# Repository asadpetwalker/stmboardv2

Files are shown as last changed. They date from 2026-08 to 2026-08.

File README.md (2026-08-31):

# stmboardv2

# What it is and why I made it
Initially, this was a standard better stm dev board, but as I progressed with this project, I realized I didn't want to do the exact same thing I did last time, so I added sensors and wireless capabilities, a speaker and more interfacing options, for extra security layers. Additionally, I added an ESP32 to sideload tasks, to add another programming option, and to add a microSD card peripheral to store more memory on my board. I made it because the STM is an extremely powerful chip, and my last board didn't do it justice from the lack of capabilities and GPIO, as well as the lack of indication leds and in general less than apt design. Thus, I spent much more time integrating multiple sensors and features, adding indicator LEDs and in general making it much more powerful and useful than a just a simple dev board.

# Assembly Instructions
1. Solder

# Pictures


Screenshot from 2026-08-30 23-37-19

# Bill of Materials

| LCSC# | MPN | Manufacturer | Package | Description | Quantity | Total Price ($) | Product Link |
|:---|:---|:---|:---|:---|---:|---:|:---|
| C29936 | CL10B105KA8NNNC | Samsung Electro-Mechanics | 0603 | 1uF ±10% 25V Ceramic Capacitor X7R 0603 | 20 | 0.43 | [Link](https://www.lcsc.com/product-detail/C29936.html) |
| C1705 | CL10A475KP8NNNC | Samsung Electro-Mechanics | 0603 | 4.7uF ±10% 10V Ceramic Capacitor X5R 0603 | 50 | 1 | [Link](https://www.lcsc.com/product-detail/C1705.html) |
| C13738 | X322516MLB4SI | YXC Crystal Oscillators | SMD3225-4P | Crystal 16MHz ±10ppm 9pF SMD3225-4P | 5 | 0.47 | [Link](https://www.lcsc.com/product-detail/C13738.html) |
| C164170 | 472192001 | MOLEX | SMD | Micro SD card (TF card) Connector and Ejector Hinged Lid Surface Mount | 1 | 0.73 | [Link](https://www.lcsc.com/product-detail/C164170.html) |
| C2933084  | FRC0402F2702TS | FOJAN | 0402 | 27kΩ ±1% 62.5mW 0402 Thick Film Resistor | 100 | 0.19 | [Link](https://www.lcsc.com/product-detail/C2933084.html)  |
| C2909342  | FRC0402F2700TS | FOJAN | 0402 | 270Ω ±1% 62.5mW 0402 Thick Film Resistor | 100 | 0.25 | [Link](https://www.lcsc.com/product-detail/C2909342.html)  |
| C1550542  | CP2102N-A02-GQFN20  | SILICON LABS | QFN-20-EP(3x3)  | USB to UART 3Mbps QFN-20-EP(3x3) Controllers RoHS | 1 | 2.29 | [Link](https://www.lcsc.com/product-detail/C1550542.html)  |
| C5656610  | ICS-43434 | TDK InvenSense | LGA-6(3.5x2.7)  | Omnidirectional -26dB 64dB LGA-6(3.5x2.7) Microphones RoHS | 1 | 4.13 | [Link](https://www.lcsc.com/product-detail/C5656610.html)  |
| C94355 | STM32F411RET6 | ST | LQFP-64(10x10)  | ARM Cortex-M4 32 Bit 100MHz LQFP-64(10x10) Microcontrollers RoHS | 1 | 6.87 | [Link](https://www.lcsc.com/product-detail/C94355.html) |
| C2913198  | ESP32-S3-WROOM-1-N8 | ESPRESSIF | SMD,25.5x18mm | 2.4GHz ESP32-S3 Chip On-board PCB Antenna -98.2dBm SMD,25.5x18mm RF Transceiver Modules and Modems RoHS | 1 | 4.91 | [Link](https://www.lcsc.com/product-detail/C2913198.html)  |
| C22365428 | AP2112K-1.8TRG1(MS) | MSKSEMI | SOT-23-5 | Linear Voltage Regulator IC Positive Fixed 1 Output 600mA SOT-23-5 | 5 | 0.48 | [Link](https://www.lcsc.com/product-detail/C22365428.html) |
| C726001 | ICM-20948 | TDK InvenSense | QFN-24(3x3) | QFN-24(3x3) IMUs (Inertial Measurement Units) RoHS | 1 | 18.96 | [Link](https://www.lcsc.com/product-detail/C726001.html) |
| C22469962 | TXB0102DCT(LX) | lingxingic | TSSOP-8 | 45Mbps 1 2 TSSOP-8 Translators, Level Shifters | 5 | 1.25 | [Link](https://www.lcsc.com/product-detail/C22469962.html) |
| C910544 | MAX98357AETE+T | MAXIM | TQFN-16-EP(3x3) | 2.4mA 2.5V~5.5V 3.2Wx1@4Ω Class D TQFN-16-EP(3x3) Audio Amplifiers RoHS | 1 | 1.32 | [Link](https://www.lcsc.com/product-detail/C910544.html) |
| C880859 | 0603N9R0C500CT | Walsin | 0603 | 9pF 50V Ceramic Capacitor NP0 0603 | 50 | 0.45 | [Link](https://www.lcsc.com/product-detail/C880859.html) |
| - | Custom PCB | JLCPCB | - | Custom printed circuit board | 5 | 8.34 | - |
| - | Shipping | - | - | Shipping cost | 1 | 18 | - |

**Total Estimated Cost:** $70.07

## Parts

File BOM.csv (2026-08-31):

Index | LCSC# | MPN | Manufacturer | Package | Customer # | Description | RoHS | Quantity | MOQ | Multiple | Unit Price($) | Extended Price($) | Product Link
1 | C29936 | CL10B105KA8NNNC | Samsung Electro-Mechanics | 0603 |  | 1uF ±10% 25V Ceramic Capacitor X7R 0603 | yes | 20 | 10 | 10 | 0.0216 | 0.43 | https://www.lcsc.com/product-detail/C29936.html
2 | C1705 | CL10A475KP8NNNC | Samsung Electro-Mechanics | 0603 |  | 4.7uF ±10% 10V Ceramic Capacitor X5R 0603 | yes | 50 | 50 | 50 | 0.0199 | 1.0 | https://www.lcsc.com/product-detail/C1705.html
3 | C13738 | X322516MLB4SI | YXC Crystal Oscillators | SMD3225-4P |  | Crystal 16MHz ±10ppm 9pF SMD3225-4P | yes | 5 | 5 | 5 | 0.0939 | 0.47 | https://www.lcsc.com/product-detail/C13738.html
4 | C164170 | 472192001 | MOLEX | SMD |  | Micro SD card (TF card) Connector and Ejector Hinged Lid Surface Mount | yes | 1 | 1 | 1 | 0.7313 | 0.73 | https://www.lcsc.com/product-detail/C164170.html
5 | C2933084 | FRC0402F2702TS | FOJAN | 0402 |  | 27kΩ ±1% 62.5mW 0402 Thick Film Resistor | yes | 100 | 100 | 100 | 0.0019 | 0.19 | https://www.lcsc.com/product-detail/C2933084.html
6 | C2909342 | FRC0402F2700TS | FOJAN | 0402 |  | 270Ω ±1% 62.5mW 0402 Thick Film Resistor | yes | 100 | 100 | 100 | 0.0025 | 0.25 | https://www.lcsc.com/product-detail/C2909342.html
7 | C1550542 | CP2102N-A02-GQFN20 | SILICON LABS | QFN-20-EP(3x3) |  | USB to UART 3Mbps QFN-20-EP(3x3) Controllers RoHS | yes | 1 | 1 | 1 | 2.2884 | 2.29 | https://www.lcsc.com/product-detail/C1550542.html
8 | C5656610 | ICS-43434 | TDK InvenSense | LGA-6(3.5x2.7) |  | Omnidirectional -26dB 64dB LGA-6(3.5x2.7) Microphones RoHS | yes | 1 | 1 | 1 | 4.1262 | 4.13 | https://www.lcsc.com/product-detail/C5656610.html
9 | C94355 | STM32F411RET6 | ST | LQFP-64(10x10) |  | ARM Cortex-M4 32 Bit 100MHz LQFP-64(10x10) Microcontrollers RoHS | yes | 1 | 1 | 1 | 6.8707 | 6.87 | https://www.lcsc.com/product-detail/C94355.html
10 | C2913198 | ESP32-S3-WROOM-1-N8 | ESPRESSIF | SMD,25.5x18mm |  | 2.4GHz ESP32-S3 Chip On-board PCB Antenna -98.2dBm SMD,25.5x18mm RF Transceiver Modules and Modems RoHS | yes | 1 | 1 | 1 | 4.91 | 4.91 | https://www.lcsc.com/product-detail/C2913198.html
11 | C22365428 | AP2112K-1.8TRG1(MS) | MSKSEMI | SOT-23-5 |  | Linear Voltage Regulator IC Positive Fixed 1 Output 600mA SOT-23-5 | yes | 5 | 5 | 5 | 0.0959 | 0.48 | https://www.lcsc.com/product-detail/C22365428.html
12 | C726001 | ICM-20948 | TDK InvenSense | QFN-24(3x3) |  | QFN-24(3x3) IMUs (Inertial Measurement Units) RoHS | yes | 1 | 1 | 1 | 18.9576 | 18.96 | https://www.lcsc.com/product-detail/C726001.html
13 | C22469962 | TXB0102DCT(LX) | lingxingic | TSSOP-8 |  | 45Mbps 1 2 TSSOP-8 Translators, Level Shifters | yes | 5 | 5 | 5 | 0.2506 | 1.25 | https://www.lcsc.com/product-detail/C22469962.html
14 | C910544 | MAX98357AETE+T | MAXIM | TQFN-16-EP(3x3) |  | 2.4mA 2.5V~5.5V 3.2Wx1@4Ω Class D TQFN-16-EP(3x3) Audio Amplifiers RoHS | yes | 1 | 1 | 1 | 1.3247 | 1.32 | https://www.lcsc.com/product-detail/C910544.html
15 | C880859 | 0603N9R0C500CT | Walsin | 0603 |  | 9pF 50V Ceramic Capacitor NP0 0603 | yes | 50 | 50 | 50 | 0.009 | 0.45 | https://www.lcsc.com/product-detail/C880859.html
16 | - | Custom PCB | JLCPCB | - |  | Custom printed circuit board | - | 5 | - | - | 1.668 | 8.34 | -
17 | - | Shipping | - | - |  | Shipping cost | - | 1 | - | - | 18.0 | 18.0 | -

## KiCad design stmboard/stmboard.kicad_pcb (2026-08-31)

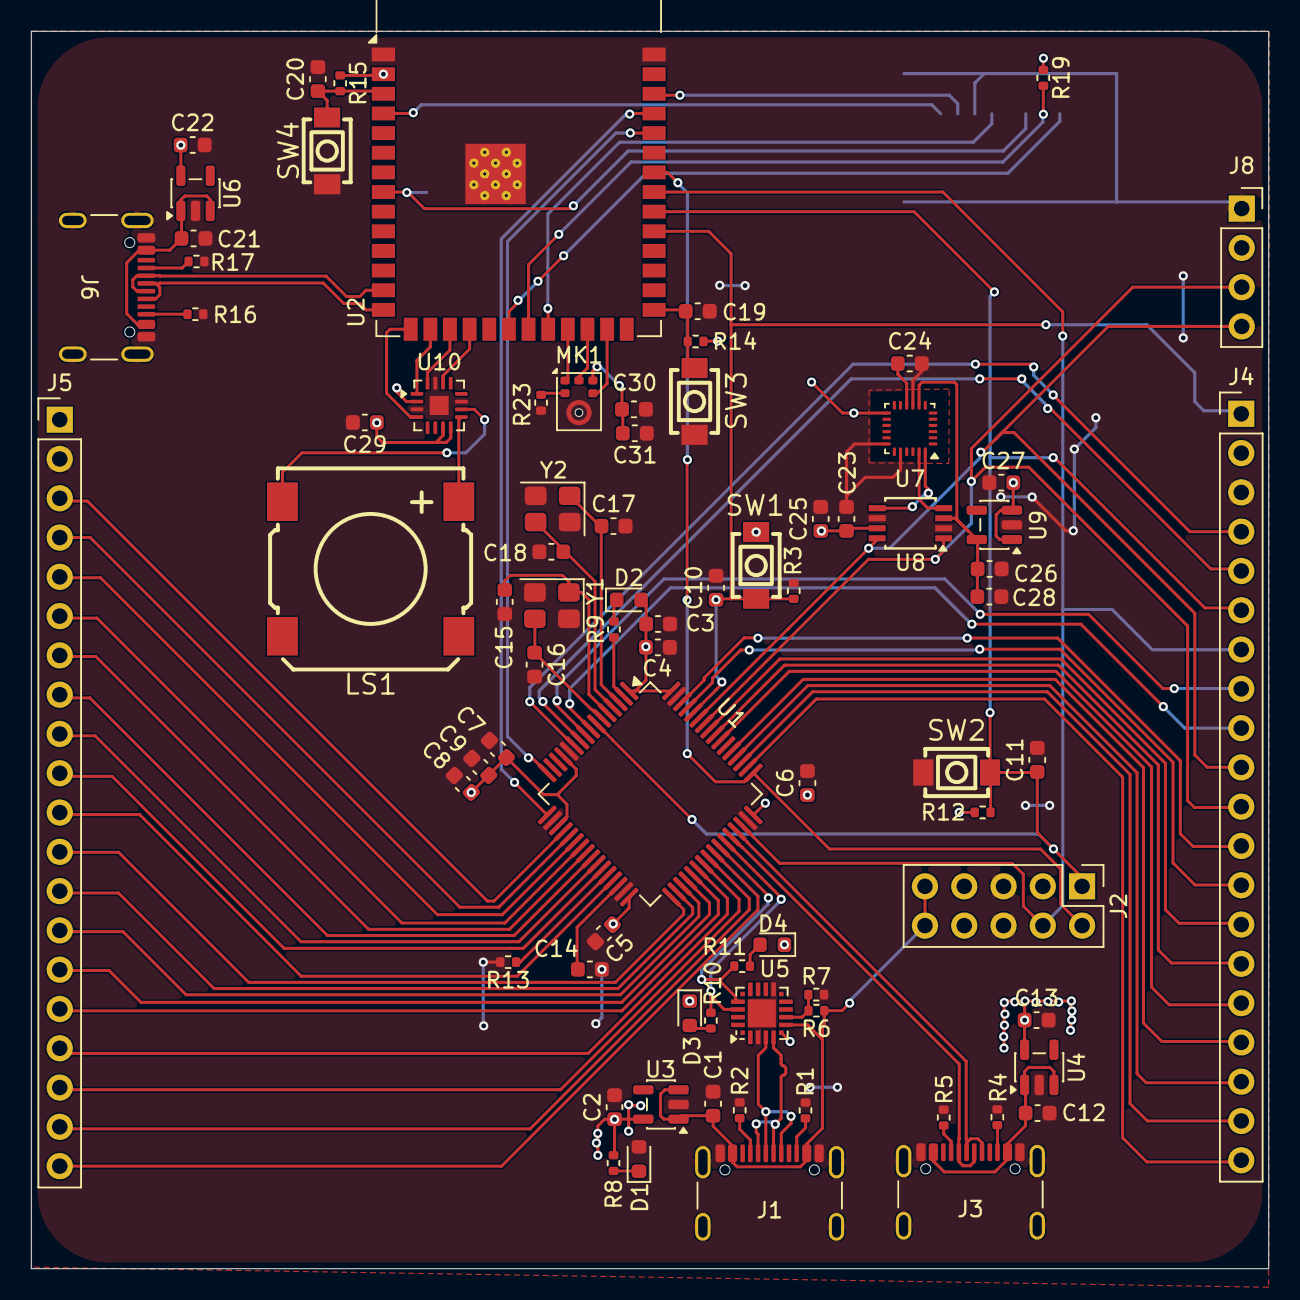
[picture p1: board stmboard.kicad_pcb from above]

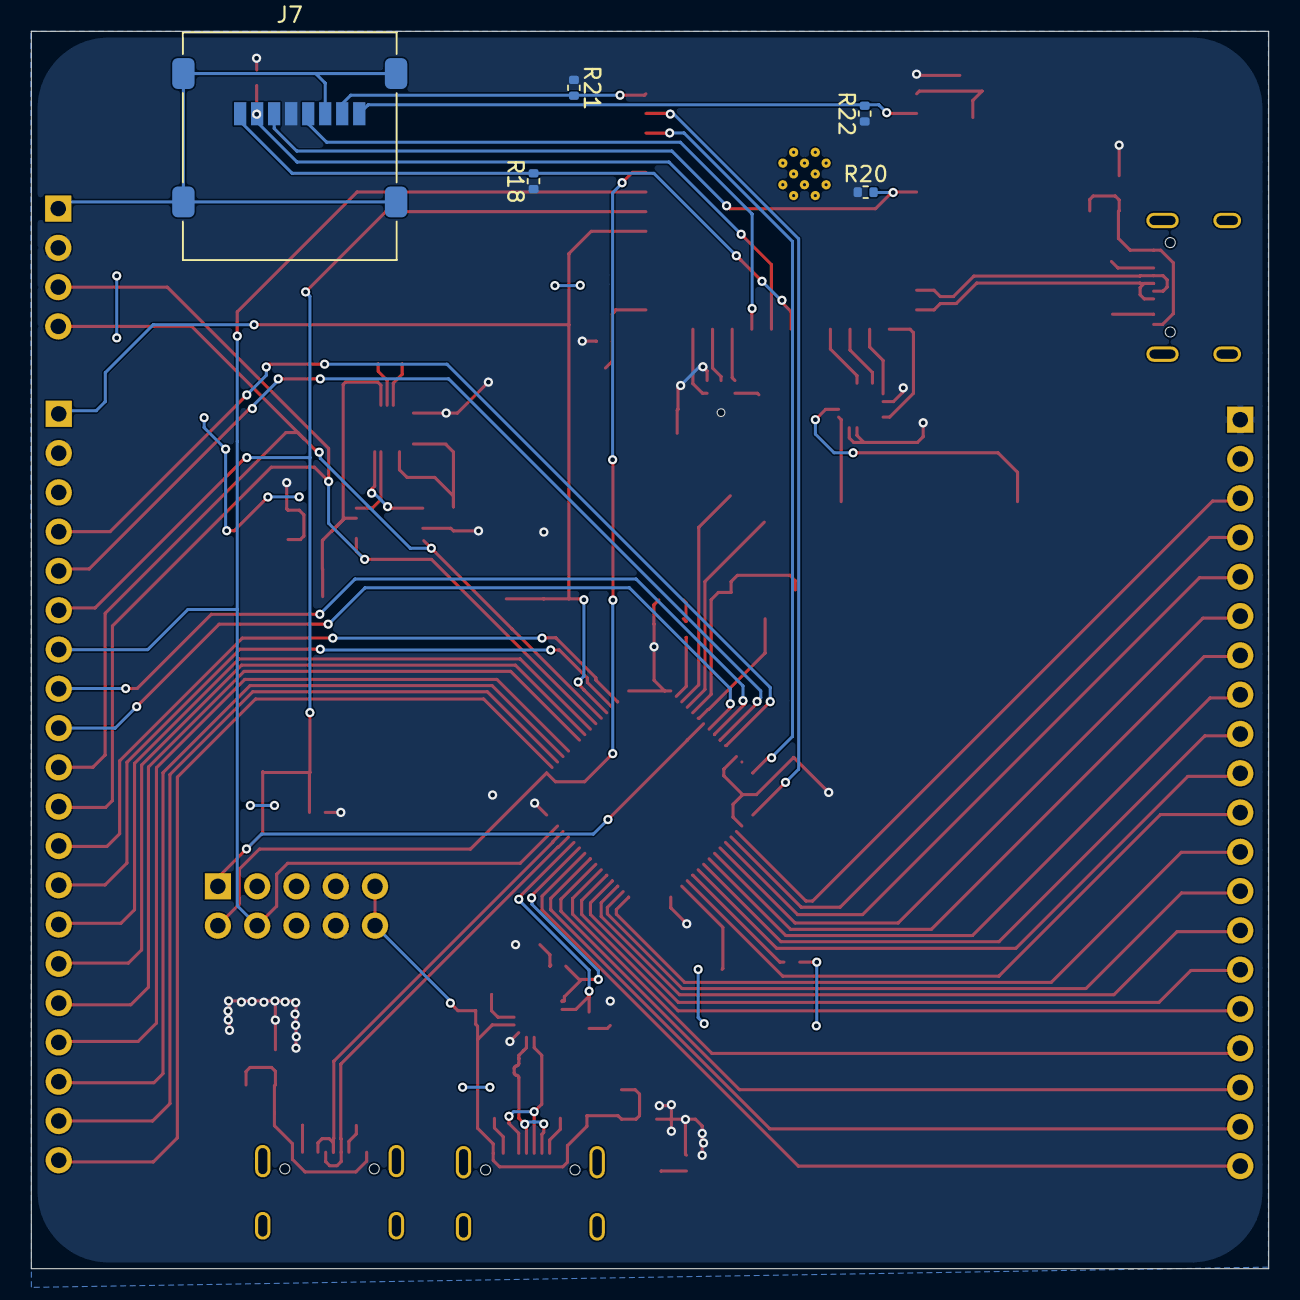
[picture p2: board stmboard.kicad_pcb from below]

Board: 2 copper layers, 80.0 x 80.0 mm, 84 parts (5 on the bottom side), 92 nets.

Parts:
C1, C2, C9, C12, C13, C21, C22, C27, C28: 1u; C_0603_1608Metric
C3, C4, C5, C6, C7, C10, C11, C14, C19, C20, C23, C24, C25, C26, C29, C30, C31: 100n; C_0603_1608Metric
C8: 4.7u; C_0603_1608Metric
C15, C16, C17, C18: 18p; C_0603_1608Metric
D1, D2: LED; LED_0603_1608Metric
D3: TX; LED_0603_1608Metric
D4: RX; LED_0603_1608Metric
J1, J3, J6: USB_C_Receptacle_USB2.0_14P; USB_C_Receptacle_GCT_USB4105-xx-A_16P_TopMnt_Horizontal
J2: Conn_02x05_Odd_Even; PinHeader_2x05_P2.54mm_Vertical
J4, J5: Conn_01x20_Socket; PinHeader_1x20_P2.54mm_Vertical
J7: Micro_SD_Card; microSD_HC_Molex_47219-2001
J8: Conn_01x04; PinSocket_1x04_P2.54mm_Vertical
LS1: Speaker; BUZ-SMD_4P-L13.0-W13.0-P11.4-BL
MK1: SPH0645LM4H; Knowles_SPH0645LM4H-6_3.5x2.65mm
R1, R2, R4, R5, R16, R17: 5.1k; R_0402_1005Metric
R3, R7, R12, R13, R14, R15, R18, R19, R20, R21, R22, R23: 10k; R_0402_1005Metric
R6: 27k; R_0402_1005Metric
R8, R9: 1k; R_0402_1005Metric
R10, R11: 270; R_0402_1005Metric
SW1: BOOT0; KEY-SMD_L4.0-W3.0-LS4.9-1
SW2: NRST; KEY-SMD_L4.0-W3.0-LS4.9-1
SW3, SW4: BOOT; KEY-SMD_L4.0-W3.0-LS4.9-1
U1: STM32F411RCTx; LQFP-64_10x10mm_P0.5mm
U2: ESP32-S3-WROOM-1
U3, U4, U6: AP2112K-3.3; SOT-23-5
U5: CP2102N-Axx-xQFN20; SiliconLabs_QFN-20-1EP_3x3mm_P0.5mm_EP1.8x1.8mm
U7: ICM-20948; InvenSense_QFN-24_3x3mm_P0.4mm
U8: TXB0102DCT; TSSOP-8_3x3mm_P0.65mm
U9: AP2112K-1.8; SOT-23-5
U10: MAX98357A; TQFN-16-1EP_3x3mm_P0.5mm_EP1.23x1.23mm
Y1: 25MHz; Crystal_SMD_Abracon_ABM8G-4Pin_3.2x2.5mm
Y2: 32.768KHz; Crystal_SMD_Abracon_ABM8G-4Pin_3.2x2.5mm

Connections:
+1V8: C26.1, C28.1, U7.8 (VDDIO), U8.3 (VCCA), U9.5 (VOUT)
+3V3: C2.1, C3.1, C4.1, C5.1, C6.1, C7.1, C8.1, C9.1, C13.1, C22.1, C23.1, C25.1, C27.1, C29.1, C30.1, C31.1, D2.2 (A), D3.1 (K), D4.1 (K), J2.7, J2.8, J4.2, J5.1, J7.4 (VDD), J8.2, MK1.5 (VDD), R8.1, R12.1, R14.1, R15.1, R18.1, R19.1, R20.1, R21.1, R22.1, SW1.2, U1.1 (VBAT), U1.13 (VDDA), U1.19 (VDD), U1.32 (VDD), U1.48 (VDD), U1.64 (VDD), U2.2 (3V3), U3.5 (VOUT), U4.5 (VOUT), U5.6 (VDD), U6.5 (VOUT), U7.13 (VDD), U8.7 (VCCB), U9.1 (VIN), U9.3 (EN), U10.2 (GAIN_SLOT), U10.7 (VDD), U10.8 (VDD)
/BCLK: U2.17 (IO9), U10.16 (BCLK)
/BCLK2: MK1.4 (BCLK), U2.25 (IO48)
/BOOT0: C10.1, J4.1, R3.1, SW1.1, U1.60 (BOOT0), U2.31 (IO38)
/CLK: J7.5 (CLK), U2.22 (IO14)
/CMD: J7.3 (CMD), R20.2, U2.8 (IO15)
/D+: J3.A6 (D+), J3.B6 (D+), U1.45 (PA12)
/D-: J3.A7 (D-), J3.B7 (D-), U1.44 (PA11)
/DAT0: J7.7 (DAT0), R21.2, U2.38 (IO2)
/DAT1: J7.8 (DAT1), R22.2, U2.4 (IO4)
/DAT2: J7.1 (DAT2), R18.2, U2.20 (IO12)
/DAT3: J7.2 (DAT3/CD), R19.2, U2.21 (IO13)
/DATA: MK1.6 (DATA), U2.24 (IO47)
/DIN: U2.16 (IO46), U10.1 (DIN)
/D_{0}+: J1.A6 (D+), J1.B6 (D+), U5.4 (D+)
/D_{0}-: J1.A7 (D-), J1.B7 (D-), U5.5 (D-)
/D_{1}+: J6.A6 (D+), J6.B6 (D+), U2.14 (USB_D+)
/D_{1}-: J6.A7 (D-), J6.B7 (D-), U2.13 (USB_D-)
/FCLK: U2.18 (IO10), U10.14 (LRCLK)
/NRST: C11.1, J2.1, J4.6, R12.2, SW2.1, U1.7 (NRST), U2.32 (IO39)
/OSC_{IN}: C15.1, U1.5 (PH0), Y1.1
/OSC_{OUT}: C16.1, U1.6 (PH1), Y1.3
/PA4: J5.3, U1.20 (PA4)
/PA5: J5.4, U1.21 (PA5)
/PA6: J5.5, U1.22 (PA6)
/PA7: J5.6, U1.23 (PA7)
/PA8: J5.20, U1.41 (PA8)
/PA15: J4.20, U1.50 (PA15)
/PB0: J5.9, U1.26 (PB0)
/PB1: J5.10, U1.27 (PB1)
/PB2: R13.1, U1.28 (PB2)
/PB3: J4.16, U1.55 (PB3)
/PB4: J4.15, U1.56 (PB4)
/PB5: J4.14, U1.57 (PB5)
/PB6: J4.11, J8.3, U1.58 (PB6), U8.1 (B2)
/PB7: J4.10, J8.4, U1.59 (PB7), U8.8 (B1)
/PB8: J4.13, U1.61 (PB8)
/PB9: J4.12, U1.62 (PB9)
/PB10: J5.11, U1.29 (PB10)
/PB12: J5.12, U1.33 (PB12)
/PB13: J5.13, U1.34 (PB13)
/PB14: J5.15, U1.36 (PB15)
/PB15: J5.14, U1.35 (PB14)
/PC0: J4.9, U1.8 (PC0)
/PC1: J4.8, U1.9 (PC1)
/PC2: J4.5, U1.10 (PC2)
/PC3: J4.4, U1.11 (PC3)
/PC4: J5.7, U1.24 (PC4)
/PC5: J5.8, U1.25 (PC5)
/PC6: J5.16, U1.37 (PC6)
/PC7: J5.17, U1.38 (PC7)
/PC8: J5.18, U1.39 (PC8)
/PC9: J5.19, U1.40 (PC9)
/PC10: J4.19, U1.51 (PC10)
/PC11: J4.18, U1.52 (PC11)
/PC12: J4.17, U1.53 (PC12)
/PC13: R9.1, U1.2 (PC13)
/PC14: C17.1, U1.3 (PC14), Y2.1
/PC15: C18.1, U1.4 (PC15), Y2.3
/RX: R11.1, U1.42 (PA9), U5.17 (RXD)
/RX1: U1.17 (PA3), U2.37 (TXD0)
/SCL_{1V8}: U7.23 (SCL/SCLK), U8.4 (A2)
/SDA_{1V8}: U7.24 (SDA/SDI), U8.5 (A1)
/SWCLK: J2.2, U1.49 (PA14), U2.34 (IO41)
/SWDIO: J2.4, J4.7, U1.46 (PA13), U2.33 (IO40)
/TX: R10.1, U1.43 (PA10), U5.18 (TXD)
/TX1: U1.16 (PA2), U2.36 (RXD0)
/VBUS: C1.1, J1.A4 (VBUS), J1.A9 (VBUS), J1.B4 (VBUS), J1.B9 (VBUS), J2.9, J2.10, R6.1, U3.1 (VIN), U3.3 (EN), U5.7 (VREGIN)
/WS: MK1.1 (WS), U2.23 (IO21)
/~SD_MODE: U2.15 (IO3), U10.4 (~SD_MODE)
GND: C1.2, C2.2, C3.2, C4.2, C5.2, C6.2, C7.2, C8.2, C9.2, C10.2, C11.2, C12.2, C13.2, C14.2, C15.2, C16.2, C17.2, C18.2, C19.2, C20.2, C21.2, C22.2, C23.2, C24.2, C25.2, C26.2, C27.2, C28.2, C29.2, C30.2, C31.2, D1.2 (A), J1.A1 (GND), J1.A12 (GND), J1.B1 (GND), J1.B12 (GND), J1.SH (SHIELD), J2.5, J2.6, J3.A1 (GND), J3.A12 (GND), J3.B1 (GND), J3.B12 (GND), J3.SH (SHIELD), J4.3, J5.2, J6.A1 (GND), J6.A12 (GND), J6.B1 (GND), J6.B12 (GND), J6.SH (SHIELD), J7.6 (VSS), J7.SH (SHIELD), J8.1, MK1.3 (GND), R1.2, R2.1, R3.2, R4.2, R5.1, R7.2, R13.2, R16.2, R17.1, R23.2, SW2.2, SW3.1, SW4.1, U1.12 (VSSA), U1.18 (VSS), U1.31 (VSS), U1.47 (VSS), U1.63 (VSS), U2.1 (GND), U2.40 (GND), U2.41 (GND), U3.2 (GND), U4.2 (GND), U5.3 (GND), U5.12 (GND), U5.21 (GND), U6.2 (GND), U7.9 (SDO/AD0), U7.18 (GND), U7.20 (GND), U8.2 (GND), U8.6 (OE), U9.2 (GND), U10.3 (GND), U10.11 (GND), U10.15 (GND), U10.17 (PAD), Y1.2 (G), Y1.4 (G), Y2.2 (G), Y2.4 (G)
unnamed: D1.1 (K), R8.2
unnamed: D2.1 (K), R9.2
unnamed: D3.2 (A), R10.2
unnamed: D4.2 (A), R11.2
unnamed: J1.A5 (CC1), R2.2
unnamed: J1.B5 (CC2), R1.1
unnamed: J3.A5 (CC1), R5.2
unnamed: J3.B5 (CC2), R4.1
unnamed: J6.A5 (CC1), R17.2
unnamed: J6.B5 (CC2), R16.1
unnamed: MK1.2 (SEL), R23.1
unnamed: C14.1, U1.30 (VCAP1)
unnamed: C20.1, R15.2, SW4.2, U2.3 (EN)
unnamed: C19.1, R14.2, SW3.2, U2.27 (IO0)
unnamed: C12.1, J3.A4 (VBUS), J3.A9 (VBUS), J3.B4 (VBUS), J3.B9 (VBUS), U4.1 (VIN), U4.3 (EN)
unnamed: R6.2, R7.1, U5.8 (VBUS)
unnamed: C21.1, J6.A4 (VBUS), J6.A9 (VBUS), J6.B4 (VBUS), J6.B9 (VBUS), U6.1 (VIN), U6.3 (EN)
unnamed: C24.1, U7.10 (REGOUT)
unnamed: LS1.2, U10.10 (OUTN)
unnamed: LS1.1, U10.9 (OUTP)

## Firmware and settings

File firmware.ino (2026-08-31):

#include <Wire.h>
#include <Adafruit_GFX.h>
#include <Adafruit_SSD1306.h>

#define SCREEN_WIDTH 128
#define SCREEN_HEIGHT 64
#define OLED_RESET -1 
#define SCREEN_ADDRESS 0x3C 

Adafruit_SSD1306 display(SCREEN_WIDTH, SCREEN_HEIGHT, &Wire, OLED_RESET);

void setup() {
  Serial.begin(115200);

  Wire.begin(); 

  if(!display.begin(SSD1306_SWITCHCAPVCC, SCREEN_ADDRESS)) {
    while (true);
  }

  display.clearDisplay();
  
  display.setTextSize(1);
  display.setTextColor(SSD1306_WHITE);
  display.setCursor(0, 0);
  
  display.println(F("STM32Duino Initialized"));
  display.println(F("----------------------"));
  display.print(F("I2C Address: 0x"));
  display.println(SCREEN_ADDRESS, HEX);
  display.println(F("Status: ONLINE"));

  display.display();
}

void loop() {
  display.fillCircle(120, 56, 4, SSD1306_WHITE);
  display.display();
  delay(500);
  
  display.fillCircle(120, 56, 4, SSD1306_BLACK);
  display.display();
  delay(500);
}

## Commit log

2026-08-30 stm projected pinout
    [stmboard.kicad_pcb, stmboard.kicad_sch]
2026-08-30 workingon schematic crystals ldos usb cp2102 leds
    [stmboard.kicad_sch]
2026-08-30 sd card sdmmc esp32
    [stmboard.kicad_sch]
2026-08-30 9 dof + voltage reg
    [stmboard.kicad_sch]
2026-08-30 mic + footprints
    [stmboard.kicad_sch]
2026-08-31 pcb + footprints
    [stmboard-B_Cu.gbr, stmboard-B_Mask.gbr, stmboard-B_Paste.gbr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]
2026-08-31 Readme
    Added detailed project description, assembly instructions, pictures, and a bill of materials with estimated costs.
2026-08-31 added BOM.csv
    [BOM.csv]
